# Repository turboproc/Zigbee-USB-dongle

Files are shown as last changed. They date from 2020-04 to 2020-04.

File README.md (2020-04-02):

# Introduction

USB dongle to host the EBYTE C1352P Zigbee module. Main features:
- E79-400DM2005S Zigbee module
- CH340E USB controller
- 2 on board leds
- button to open bootloader backdoor
- CJTAG interface through 6 pin header 
 
The 6 pin connector matches the [Zigbee dongle adapter] (https://github.com/turboproc/Zigbee-dongle-adapter) which allows easy connection to the TI CC-DEVPACK-DEBUG board.

**WARNING: this is work in progress. Designs still need to be validaded on first prototypes.**

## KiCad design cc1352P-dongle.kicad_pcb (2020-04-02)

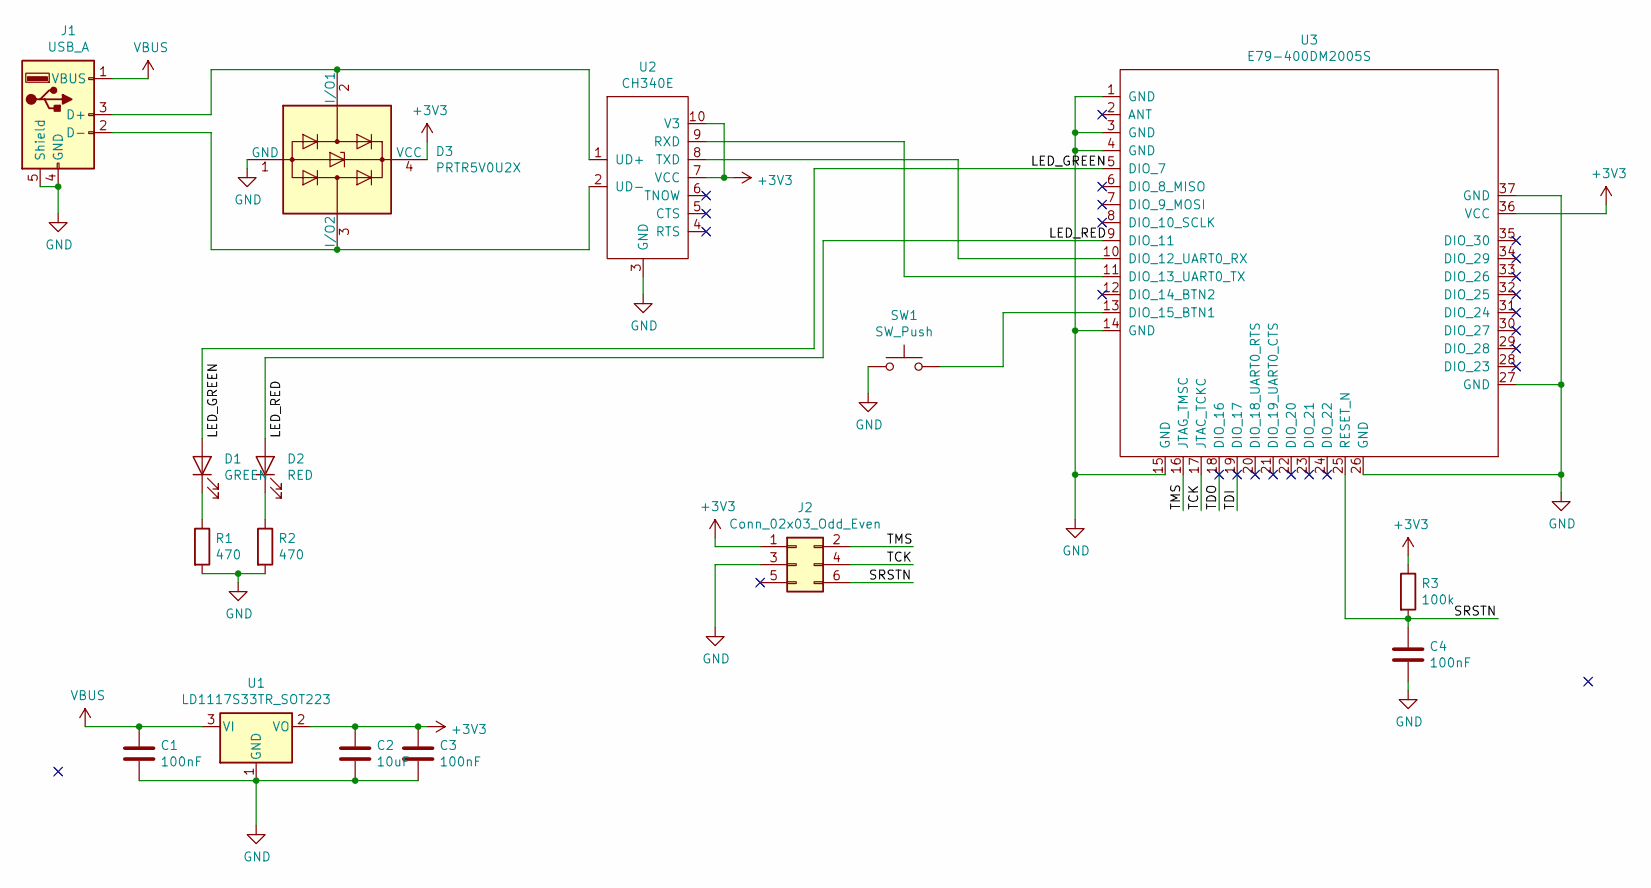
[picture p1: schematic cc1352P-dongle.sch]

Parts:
C1, C3, C4: 100nF; C_0603_1608Metric_Pad1.05x0.95mm_HandSolder
C2: 10uF; C_0603_1608Metric_Pad1.05x0.95mm_HandSolder
D1: GREEN; LED_0603_1608Metric_Pad1.05x0.95mm_HandSolder
D2: RED; LED_0603_1608Metric_Pad1.05x0.95mm_HandSolder
D3: PRTR5V0U2X; SOT-143
J1: USB_A
J2: Conn_02x03_Odd_Even; PinHeader_2x03_P2.54mm_Vertical
R1, R2: 470; R_0603_1608Metric_Pad1.05x0.95mm_HandSolder
R3: 100k; R_0603_1608Metric_Pad1.05x0.95mm_HandSolder
SW1: SW_Push; SW_SPST_B3U-3000P
U1: LD1117S33TR_SOT223; SOT-223-3_TabPin2
U2: CH340E; MSOP-10_3x3mm_P0.5mm
U3: E79-400DM2005S

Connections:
+3V3: C2.1, C3.1, D3.4 (VCC), J2.1, R3.1, U1.2 (VO), U2.7 (VCC), U2.10 (V3), U3.36 (VCC)
/LED_GREEN: D1.2 (A), U3.5 (DIO_7)
/LED_RED: D2.2 (A), U3.9 (DIO_11)
/SRSTN: C4.1, J2.6, R3.2, U3.25 (RESET_N)
/TCK: J2.4, U3.17 (JTAC_TCKC)
/TDI: U3.19 (DIO_17)
/TDO: U3.18 (DIO_16)
/TMS: J2.2, U3.16 (JTAG_TMSC)
GND: C1.2, C2.2, C3.2, C4.2, D3.1 (GND), J1.4 (GND), J1.5 (Shield), J2.3, R1.2, R2.2, SW1.1, U1.1 (GND), U2.3 (GND), U3.1 (GND), U3.3 (GND), U3.4 (GND), U3.14 (GND), U3.15 (GND), U3.26 (GND), U3.27 (GND), U3.37 (GND)
unnamed: D1.1 (K), R1.1
unnamed: D2.1 (K), R2.1
unnamed: D3.2 (I/O1), J1.3 (D+), U2.1 (UD+)
unnamed: D3.3 (I/O2), J1.2 (D-), U2.2 (UD-)
unnamed: SW1.2, U3.13 (DIO_15_BTN1)
unnamed: U2.8 (TXD), U3.10 (DIO_12_UART0_RX)
unnamed: U2.9 (RXD), U3.11 (DIO_13_UART0_TX)
VBUS: C1.1, J1.1 (VBUS), U1.3 (VI)

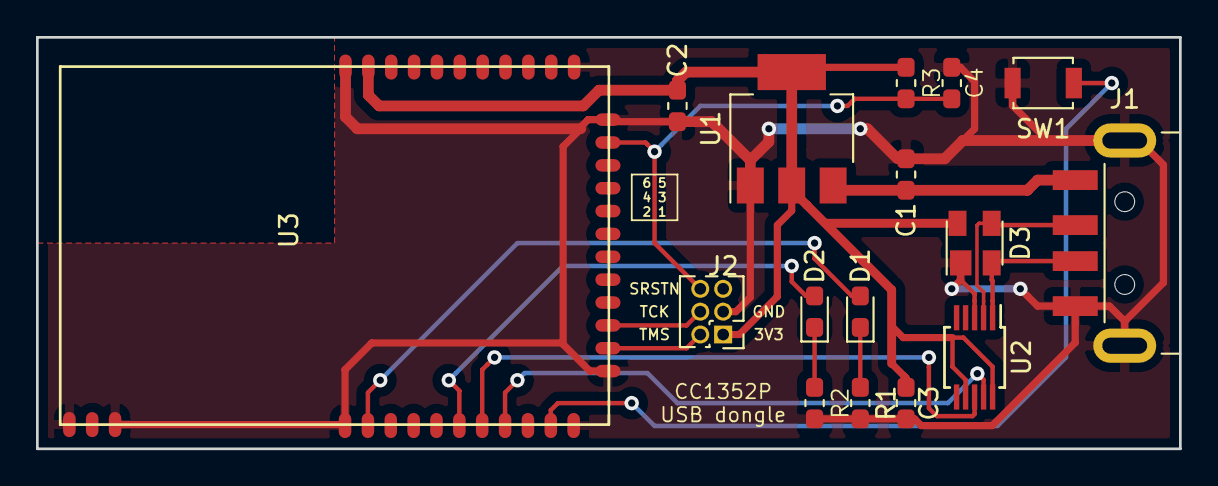
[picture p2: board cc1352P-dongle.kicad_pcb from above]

Board: 2 copper layers, 63.5 x 22.9 mm, 16 parts (0 on the bottom side), 15 nets.

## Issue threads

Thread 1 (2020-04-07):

[REQUEST] CAD-design of CC2652 USB-stick housing/enclosure and STL-files for editing and 3D-printing?

Hedda, 2020-04-07:
@turboproc Anyone working on an open-source CAD-design of a USB-stick housing/enclosure specifically made for CC2652 USB-sticks and if so would be willing to share their designs in STL file-format to enabling editing the design by others and 3D-printing?

One can, for example, get many designs and files for CC2531-based USB-dongles/USB-adapters (with or without antenna) on Thingiverse, example:

- https://www.thingiverse.com/thing:3948643
- https://www.thingiverse.com/thing:3646828
- https://www.thingiverse.com/thing:3532598
- https://www.thingiverse.com/thing:3731958

One can also buy professionally made injection moulding housings/enclosures from China via Alibaba or Aliexpress that one can take inspiration from, example:

- https://aliexpress.com/item/4000134201124.html
  - https://ae01.alicdn.com/kf/Hfb070d72fc45440497dce7d04e59d6b7d.jpg
- https://aliexpress.com/item/32855419632.html
  - https://ae01.alicdn.com/kf/H326a2ad3cfe64a318083102b0df62cd5N.jpg
  - https://ae01.alicdn.com/kf/H01eca8f47cd64bfd975738c1a4c30553i.jpg
- https://aliexpress.com/item/33007327270.html
- https://aliexpress.com/item/32852997963.html
- https://aliexpress.com/item/32690180597.html
- https://aliexpress.com/item/32847892743.html
  - https://ae01.alicdn.com/kf/HTB1K83IeXHM8KJjSZFwq6AibXXaD.jpg

By the way, I am not sure about English terminology for this, when talking about an exterior/outer protective covering for interior/inner electronic equipment in the specific context of a USB-dongle/USB-adapter like the Zig-a-zig-ah USB-stick, is the keyword called; enclosure, housing, casing, cover, case, box, shell, or another descriptive name that might be more correct?

- https://en.wikipedia.org/wiki/Housing_(engineering)
- https://en.wikipedia.org/wiki/Electrical_enclosure
- https://en.wikipedia.org/wiki/Computer_case

Hedda, 2020-04-07:
Disclaimer: I have also posted same request to @omerk on https://github.com/electrolama/zig-a-zig-ah/issues/9

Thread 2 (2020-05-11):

Some suggestions for a future revision of the board

Hedda, 2020-05-11:
@turboproc Please check out some of the related suggestion in https://github.com/electrolama/zig-a-zig-ah/issues/12
